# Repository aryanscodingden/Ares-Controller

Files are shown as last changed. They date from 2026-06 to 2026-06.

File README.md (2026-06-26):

## Ares - A game controller
A custom game controller built using a ESP32. 

Game Controller Render 4

This project was built because I always wanted to own a controller & decided to build one instead. 
It was indeed a very intersting journey to build one of my own, started to appricate the small QOL of other products.
<br>
(P.S. This is my first ever hardware project)

# Schematic

This schematic was made in KiCAD. It's a very simple controller.
<br>
It features a ESP32-NodeMCU for the main controller board & a TP4056 Module to charge the entire controller.

# PCB


# Case
This case was designed in Fusion 360. 
<p align="center">
  
  
</p>

<p align="center">
  
  
</p>

# Firmware

The firmware is written in C++ and will be edited/deployed from Arduino IDE.

# BOM
| SR NO | Item | Unit Price | URL |
|---:|---|---:|-----|
| 1 | ESP 32 NODE-MCU | ₹383 ($4.06) | https://robocraze.com/products/nodemcu-32-wifi-bluetooth-esp32-development-board30-pin |
| 2 | Joysticks | ₹269 ($2.85) | https://www.amazon.in/Robocraze-Joystick-Module-PS2-Set/dp/B086VZH739 |
| 3 | TP4056 | ₹14 ($0.15) | https://robocraze.com/products/tp4056-battery-charger-c-type-module-with-protection-1 |
| 4 | Tactile Push Button Switch Assorted Kit | ₹156 ($1.65) | https://robocraze.com/products/tactile-push-button-switch-assorted-kit-25-pieces-pack |
| 5 | Right Angle Tactile Triggers | ₹383 ($4.06) | https://www.amazon.in/Push-Button-Tactile-Switch-Height/dp/B08P5BN7JM |
| 6 | SPST Switches | ₹74 ($0.78) | https://www.amazon.in/Panel-Mount-Momentary-Button-Switch/dp/B0B54XV8D2 |
| 7 | 18650 Battery | ₹217 ($2.30) | https://robu.in/product/bak-nmc-18650-2600mah-3c-lithium-ion-3-6v-battery/ |
| 8 | 18650 Battery Holder | ₹16 ($0.17) | https://robocraze.com/products/18650-1-cell-holder |
| 9 | PCB | ₹2,138 ($22.61) | robu.in |
| 10 | 3D Print | ₹699 ($7.08) | https://www.amazon.in/PLA-3D-Flexibility-Eco-Friendly-Compatible/dp/B071D82LDV |
| **Total** |  | **₹4,349 ($45)** | |

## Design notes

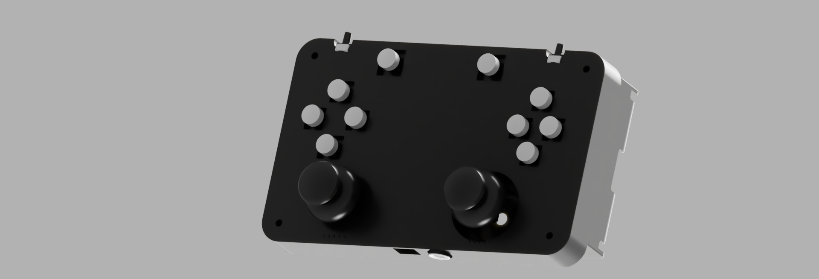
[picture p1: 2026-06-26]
Renders/Game Controller Render 2.PNG

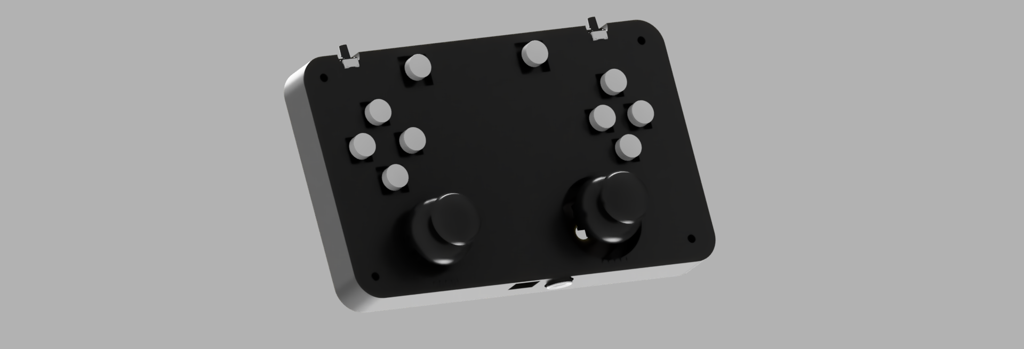
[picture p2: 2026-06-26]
Renders/Game Controller Render 1.png

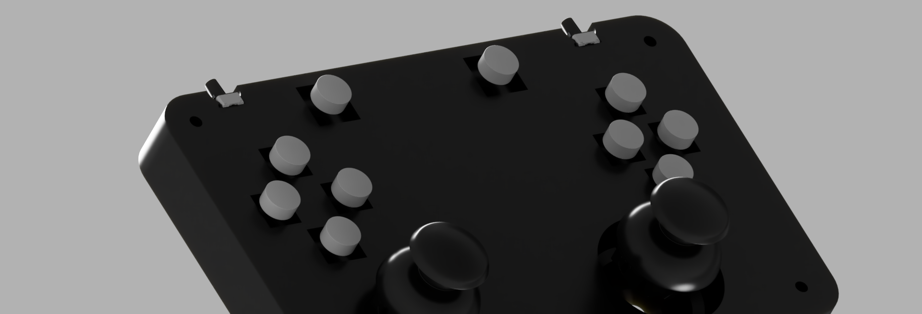
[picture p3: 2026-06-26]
Renders/Game Controller Render 4.png

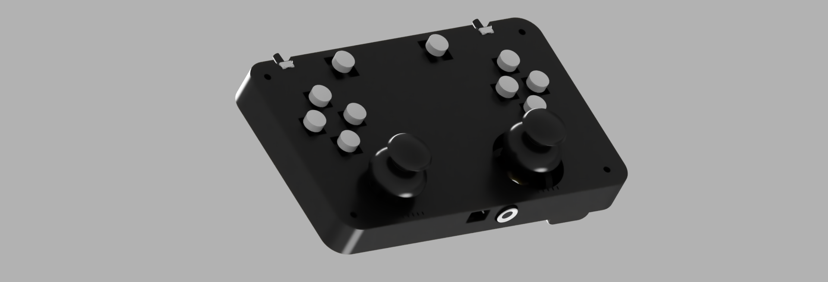
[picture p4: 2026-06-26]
Renders/Game Controller Render 3.png

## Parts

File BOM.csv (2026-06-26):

SR NO | ITEMS | UNIT PRICE | URL
1 | ESP 32 NODE-MCU | _383 ($4.06) | https://robocraze.com/products/nodemcu-32-wifi-bluetooth-esp32-development-board30-pin
2 | Joysticks | _269 ($2.85) | https://www.amazon.in/Robocraze-Joystick-Module-PS2-Set/dp/B086VZH739
3 | TP4056 | _14 ($0.15) | https://robocraze.com/products/tp4056-battery-charger-c-type-module-with-protection-1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
4 | Tactile Push Button Switch Assorted Kit | _156 ($1.65) | https://robocraze.com/products/tactile-push-button-switch-assorted-kit-25-pieces-pack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
5 | Right angle tactile trggers | _383 ($4.06) | https://www.amazon.in/Push-Button-Tactile-Switch-Height/dp/B08P5BN7JM
6 | SPST Switches | _74 ($0.78) | https://www.amazon.in/Panel-Mount-Momentary-Button-Switch/dp/B0B54XV8D2
7 | 18650 Battery | _217 ($2.30) | https://robu.in/product/bak-nmc-18650-2600mah-3c-lithium-ion-3-6v-battery/
8 | 18560 Battery holder | _16 ($0.17) | https://robocraze.com/products/18650-1-cell-holder?variant=42934046851296&country=IN&currency=INR
9 | PCB | _2138 ($22.61) | robu.in
10 | 3D print | _699 ($7.08) | https://www.amazon.in/PLA-3D-Flexibility-Eco-Friendly-Compatible/dp/B071D82LDV
 | TOTAL | _4,349 ($45)

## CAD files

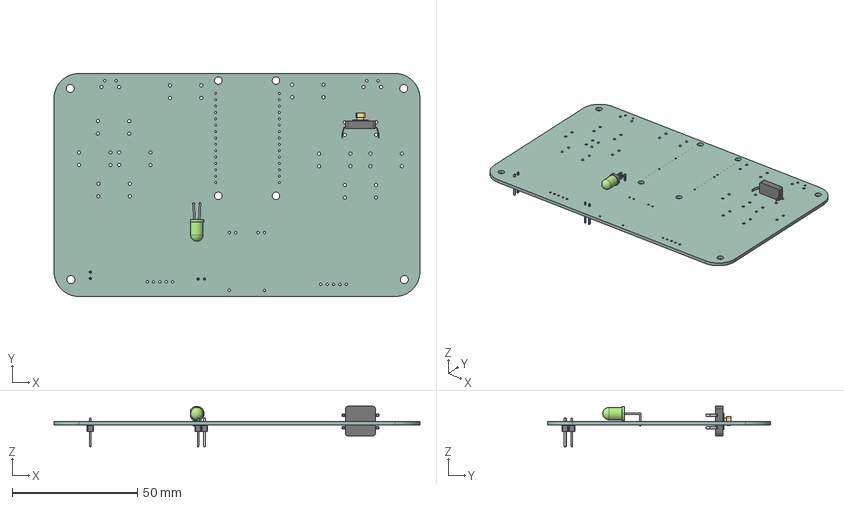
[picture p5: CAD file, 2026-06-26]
PCB Files/STEP Final.step
146.0 x 89.0 x 16.2 mm
Micro Push Button Yellow v2
LED_D5.0mm_Horizontal_O6.35mm_Z3.0mm
PinHeader_1x02_P2.54mm_Vertical x 2
GameController_PCB

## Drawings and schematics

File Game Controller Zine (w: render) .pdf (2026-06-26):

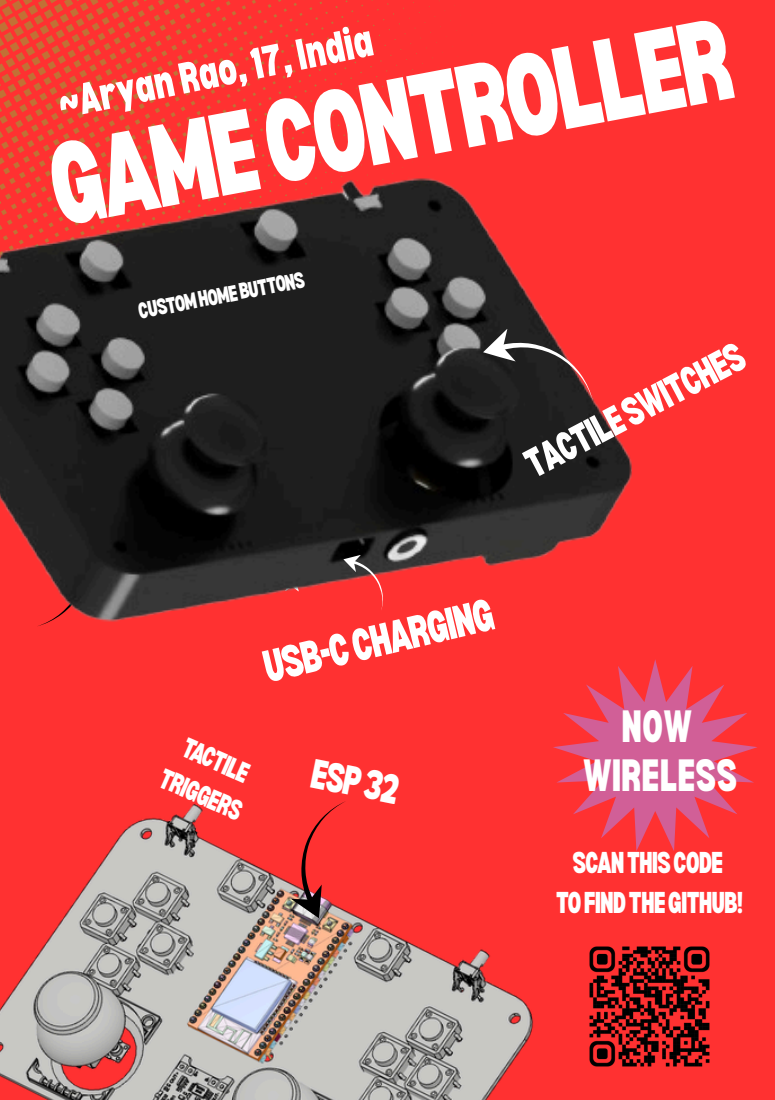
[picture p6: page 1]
USB-CCHARGING; CUSTOMHOMEBUTTONS; NOW; ESP32; WIRELESS; TACTILE TRIGGERS; TACTILESWITCHES; SCANTHISCODE TOFINDTHEGITHUB!; GAMECONTROLLER

~Aryan Rao, 17, India

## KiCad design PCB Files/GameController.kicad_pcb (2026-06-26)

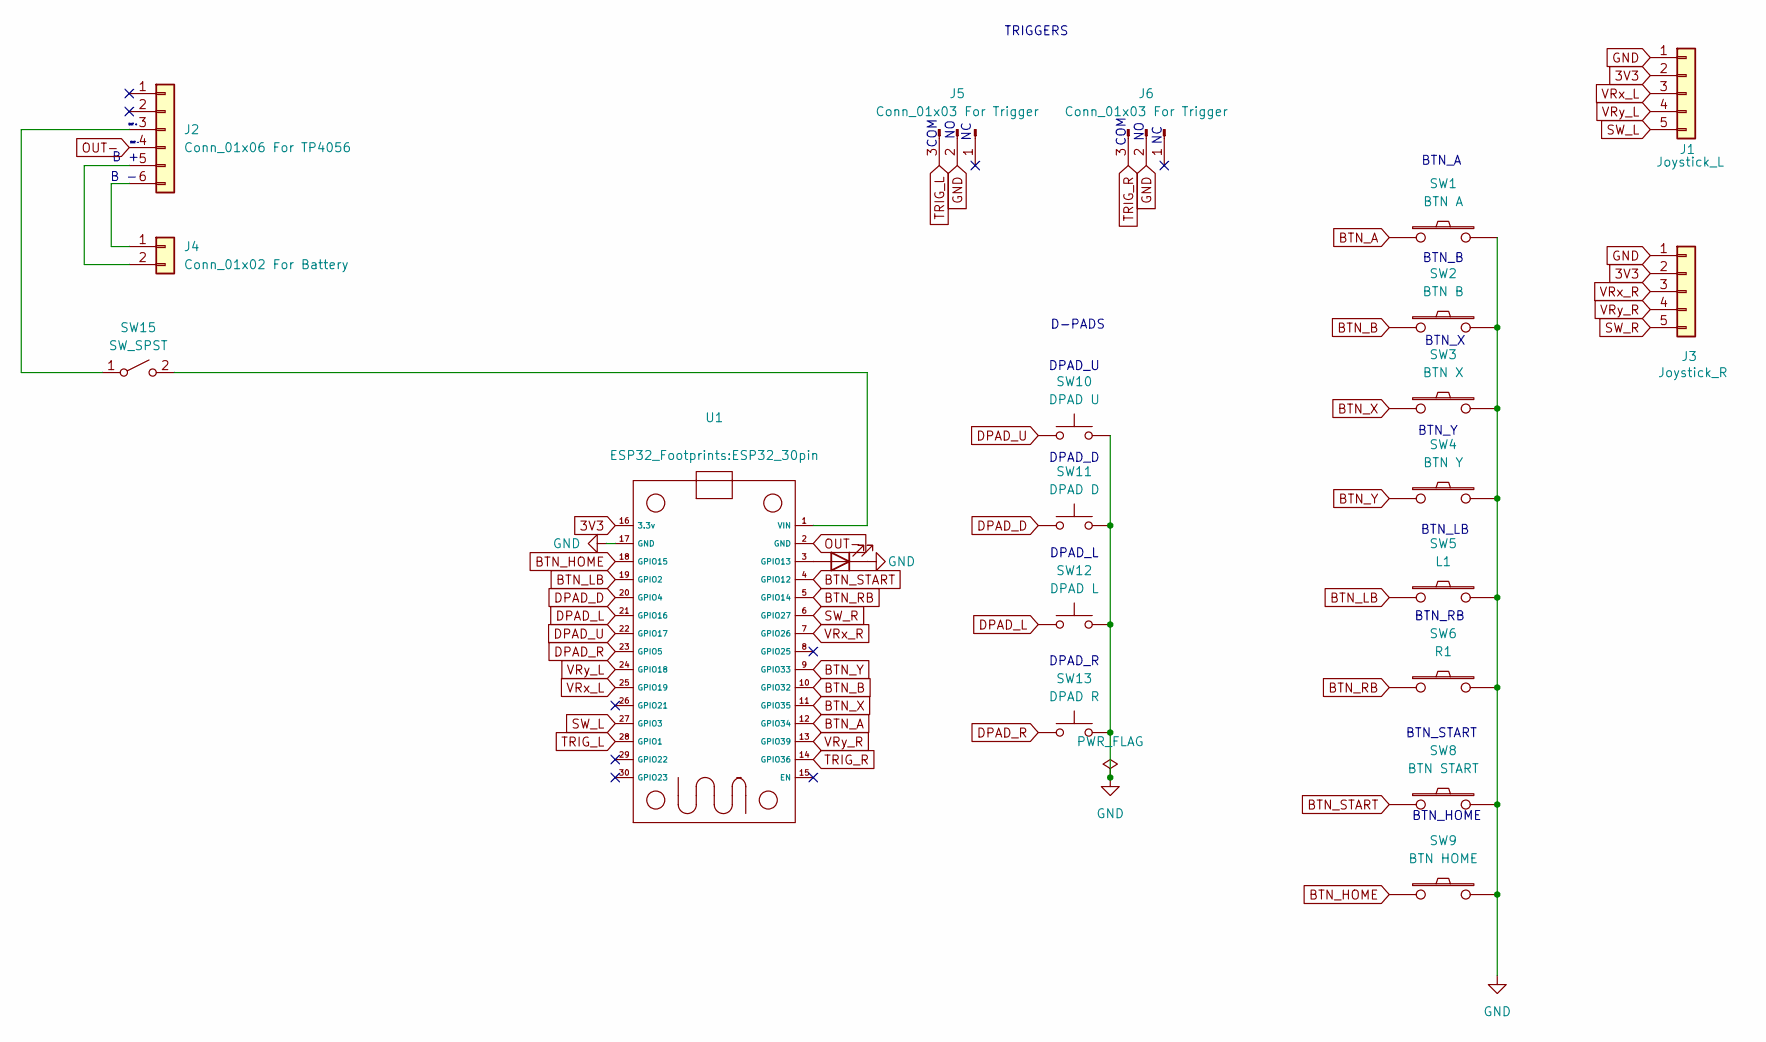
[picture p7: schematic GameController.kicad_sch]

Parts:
D1: LED; LED_D5.0mm_Horizontal_O6.35mm_Z3.0mm
J1: Joystick_L; PinHeader_1x05_P2.54mm_Horizontal
J2: Conn_01x06 For TP4056; TP4056-Module
J3: Joystick_R; PinHeader_1x05_P2.54mm_Horizontal
J4: Conn_01x02 For Battery; PinHeader_1x02_P2.54mm_Vertical
J5, J6: Conn_01x03 For Trigger
SW1: BTN A; SW_VS-1213-67-160GF
SW2: BTN B; SW_VS-1213-67-160GF
SW3: BTN X; SW_VS-1213-67-160GF
SW4: BTN Y; SW_VS-1213-67-160GF
SW5: L1; SW_Tactile_SKHH_Angled
SW6: R1; SW_Tactile_SKHH_Angled
SW8: BTN START; SW_VS-1213-67-160GF
SW9: BTN HOME; SW_VS-1213-67-160GF
SW10: DPAD U; SW_VS-1213-67-160GF
SW11: DPAD D; SW_VS-1213-67-160GF
SW12: DPAD L; SW_VS-1213-67-160GF
SW13: DPAD R; SW_VS-1213-67-160GF
SW15: SW_SPST; PinHeader_1x02_P2.54mm_Vertical
U1: ESP32_30pin

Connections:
3V3: J1.2, J3.2, U1.16 (3.3v)
BTN_A: SW1.1, U1.12 (GPIO34)
BTN_B: SW2.1, U1.10 (GPIO32)
BTN_HOME: SW9.1, U1.18 (GPIO15)
BTN_LB: SW5.1, U1.19 (GPIO2)
BTN_RB: SW6.1, U1.5 (GPIO14)
BTN_START: SW8.1, U1.4 (GPIO12)
BTN_X: SW3.1, U1.11 (GPIO35)
BTN_Y: SW4.1, U1.9 (GPIO33)
DPAD_D: SW11.1, U1.20 (GPIO4)
DPAD_L: SW12.1, U1.21 (GPIO16)
DPAD_R: SW13.1, U1.23 (GPIO5)
DPAD_U: SW10.1, U1.22 (GPIO17)
GND: D1.1 (K), J1.1, J3.1, J5.2, J6.2, SW1.2, SW2.2, SW3.2, SW4.2, SW5.2, SW6.2, SW8.2, SW9.2, SW10.2, SW11.2, SW12.2, SW13.2, U1.17 (GND)
unnamed: D1.2 (A), U1.3 (GPIO13)
unnamed: J2.3, SW15.1 (A)
unnamed: J2.5, J4.2
unnamed: J2.6, J4.1
unnamed: SW15.2 (B), U1.1 (VIN)
OUT-: J2.4, U1.2 (GND)
SW_L: J1.5, U1.27 (GPIO3)
SW_R: J3.5, U1.6 (GPIO27)
TRIG_L: J5.3, U1.28 (GPIO1)
TRIG_R: J6.3, U1.14 (GPIO36)
VRx_L: J1.3, U1.25 (GPIO19)
VRx_R: J3.3, U1.7 (GPIO26)
VRy_L: J1.4, U1.24 (GPIO18)
VRy_R: J3.4, U1.13 (GPIO39)

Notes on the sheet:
DPAD_L
DPAD_D
BTN_LB
BTN_A
B -
DPAD_R
BTN_Y
B +
BTN_START
DPAD_U
BTN_RB
COM
D-PADS
OUT +
OUT -
TRIGGERS
BTN_B
BTN_HOME
BTN_X

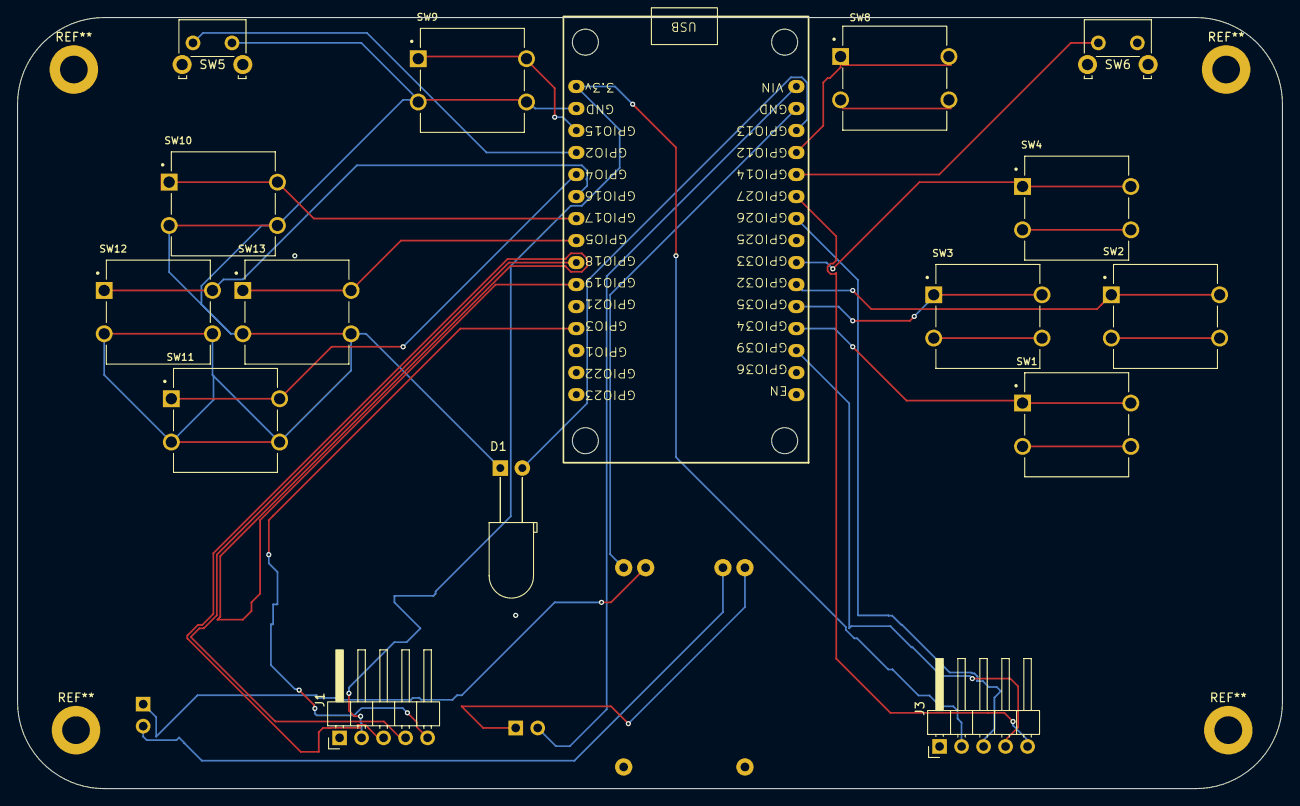
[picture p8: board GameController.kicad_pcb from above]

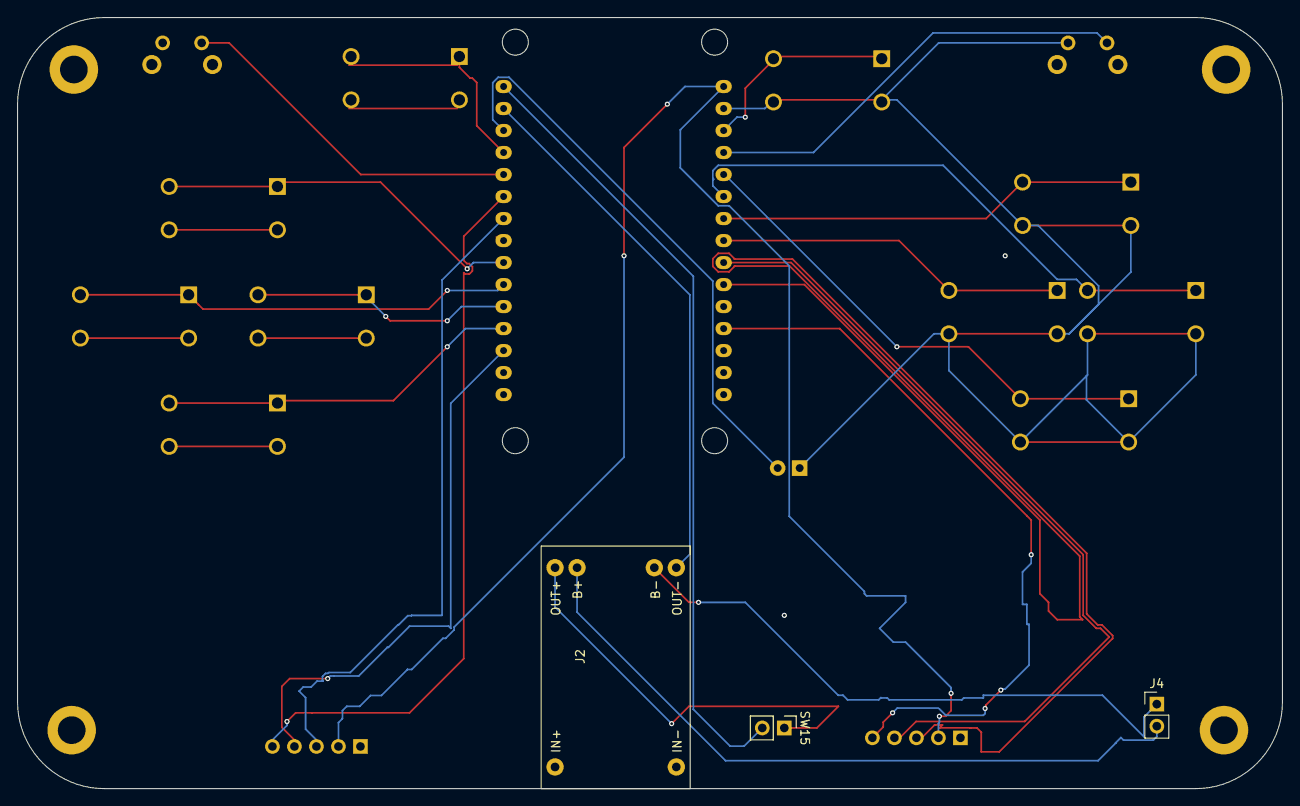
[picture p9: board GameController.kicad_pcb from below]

Board: 2 copper layers, 146.0 x 89.0 mm, 19 parts (3 on the bottom side), 26 nets.

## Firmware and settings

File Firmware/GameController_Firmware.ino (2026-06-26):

#include <BleGamepad.h>
// Initialize BLE Gamepad as Xbox Controller
BleGamepad bleGamepad("Xbox Wireless Controller", "Microsoft", 100);
// ESP32-C6 Analog Pin Mapping (Joysticks Only)
#define LEFT_STICK_X 39
#define LEFT_STICK_Y 18
#define RIGHT_STICK_X 26
#define RIGHT_STICK_Y 25
// Digital Buttons Configuration (Pin, BLE ID)
struct ButtonMapping {
uint8_t pin;
uint16_t gamepadButton;
};
ButtonMapping actionButtons[] = {
{34, BUTTON_1},  // A
{32, BUTTON_2},  // B
{33, BUTTON_3},  // X
{1, BUTTON_4},  // Y
{21, BUTTON_5},  // LB
{27, BUTTON_6},  // RB
{15,  BUTTON_9},  // Home Button
{12,  BUTTON_10}, // Start Button
};
const int numButtons = sizeof(actionButtons) / sizeof(ButtonMapping);
// Trigger Buttons
#define LEFT_TRIGGER_BTN 2
#define RIGHT_TRIGGER_BTN 14
// D-Pad Pin Assignments
#define DPAD_U 17
#define DPAD_D 4
#define DPAD_L 5
#define DPAD_R 19
void setup() {
  Serial.begin(115200);

pinMode(LEFT_STICK_X, INPUT);
pinMode(LEFT_STICK_Y, INPUT);
pinMode(RIGHT_STICK_X, INPUT);
pinMode(RIGHT_STICK_Y, INPUT);

  for (int i = 0; i < numButtons; i++) {
    pinMode(actionButtons[i].pin, INPUT_PULLUP);
  }

pinMode(LEFT_TRIGGER_BTN, INPUT_PULLUP);
pinMode(RIGHT_TRIGGER_BTN, INPUT_PULLUP);

pinMode(DPAD_U, INPUT_PULLUP);
pinMode(DPAD_D, INPUT_PULLUP);
pinMode(DPAD_L, INPUT_PULLUP);
pinMode(DPAD_R, INPUT_PULLUP);

// Configure BLE Gamepad reports
BleGamepadConfiguration bleGamepadConfig;
bleGamepadConfig.setAutoReport(false);
bleGamepadConfig.setWhichAxes(true, true, true, true, true, true, false, false);
bleGamepad.begin(&bleGamepadConfig);
Serial.println("ESP32-C6 Joystick Precision Patch Loaded!");
}
void loop() {
if (bleGamepad.isConnected()) {
// 1. Process Action & Xbox Guide buttons
for (int i = 0; i < numButtons; i++) {
if (digitalRead(actionButtons[i].pin) == LOW) {
bleGamepad.press(actionButtons[i].gamepadButton);
} else {
bleGamepad.release(actionButtons[i].gamepadButton);
}
}

if (digitalRead(LEFT_TRIGGER_BTN) == LOW) {
bleGamepad.setLeftTrigger(65535);
} else {
bleGamepad.setLeftTrigger(0);
}
if (digitalRead(RIGHT_TRIGGER_BTN) == LOW) {
bleGamepad.setRightTrigger(65535);
} else {
bleGamepad.setRightTrigger(0);
}
bool up = (digitalRead(DPAD_U) == LOW);
bool down = (digitalRead(DPAD_D) == LOW);
bool left = (digitalRead(DPAD_L) == LOW);
bool right = (digitalRead(DPAD_R) == LOW);
if (up && right) bleGamepad.setHat1(DPAD_UP_RIGHT);
else if (down && right) bleGamepad.setHat1(DPAD_DOWN_RIGHT);
else if (down && left) bleGamepad.setHat1(DPAD_DOWN_LEFT);
else if (up && left) bleGamepad.setHat1(DPAD_UP_LEFT);
else if (up) bleGamepad.setHat1(DPAD_UP);
else if (down) bleGamepad.setHat1(DPAD_DOWN);
else if (left) bleGamepad.setHat1(DPAD_LEFT);
else if (right) bleGamepad.setHat1(DPAD_RIGHT);
else bleGamepad.setHat1(HAT_CENTERED);
// Joysticks
int lsX = map(analogRead(LEFT_STICK_Y), 0, 4095, -32767, 32767);
int lsY = map(analogRead(LEFT_STICK_X), 0, 4095, -32767, 32767);
int rsX = map(analogRead(RIGHT_STICK_X), 0, 4095, -32767, 32767);
int rsY = map(analogRead(RIGHT_STICK_Y), 0, 4095, -32767, 32767);
bleGamepad.setLeftThumb(lsX, lsY);
bleGamepad.setRightThumb(rsX, rsY);
bleGamepad.sendReport();
delay(8);
}
}

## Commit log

2026-06-26 uploading files
    [GameController-B_Cu.gbr, GameController-B_Mask.gbr, GameController-B_Paste.gbr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]
2026-06-26 add BOM.csv
    [BOM.csv]
